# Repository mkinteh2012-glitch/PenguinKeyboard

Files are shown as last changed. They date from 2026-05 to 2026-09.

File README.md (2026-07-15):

# PenguinKeyboard
This is a 84 key keyboard built by @penguinmo   
Extra features on this keyboard are none! there isn't any :)  
I built this because i liked making a macropad and it's the samething as a keyboard!

## PICTURES






  





NOTE: for the Keyboard there is no source CAD because it is exported from kicad

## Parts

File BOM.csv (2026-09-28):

Item | Suplier | Quantity | Price | Shipping | Total
PCB | JLCPCB | 5 | 22.5 | 2.48
3D Print Parts | Print Legion | 1 set | 0 | 0 | going to but them made locally
Anti Slip Grip | Aliexpress | 1 set | 2.59 | 3.1
HeatSink Insert | Aliexpress | 1 set | 2.1 | N/A
Cable | Aliexpress | 1 | 2.27 | N/A
Screw m3 | Aliexpress | 1 set | 4.7 | N/A
stabilizers | Aliexpress | 1 set | 7.32 | N/A
Keycap | Aliexpress | 1 set | 23.31 | N/A
Pin Header | Aliexpress | 1 set | 2.31 | N/A
Pi Pico | Aliexpress | 1 | 4.28
Switches | Aliexpress | 100 | 15.78 | N/A
Diodes | Aliexpress | 100 | 2.4 |  | 98

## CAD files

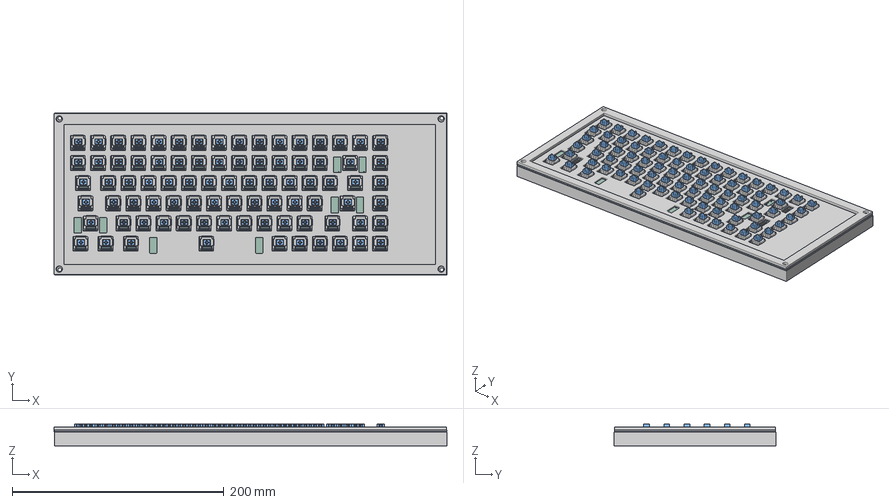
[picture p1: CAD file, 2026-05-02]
CAD/Keyboard+Assembled.stp
371.5 x 153.0 x 20.4 mm
Button x 84
Pins x 84
PenguinKeyboard 1.83.1
PenguinKeyboard 1.83.2
D_DO-35_SOD27_P7.62mm_Horizontal x 84
PenguinKeyboard_PCB

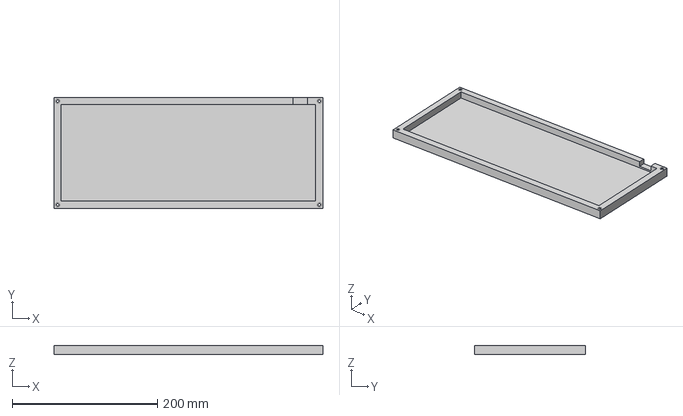
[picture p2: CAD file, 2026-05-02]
CAD/KeyboardBottom.step
371.0 x 153.0 x 13.1 mm

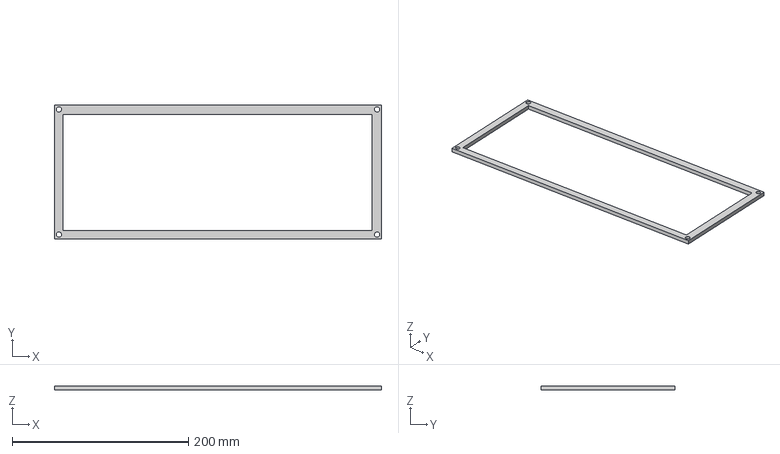
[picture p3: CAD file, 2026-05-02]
CAD/KeyboardBezel.step
371.0 x 152.0 x 5.00 mm

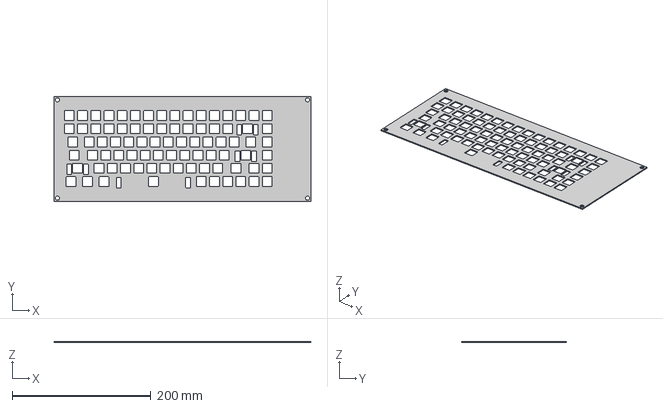
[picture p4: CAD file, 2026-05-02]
CAD/KeyboardPlate.step
371.0 x 152.0 x 1.50 mm

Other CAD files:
CAD/KeyboardPCB.step
CAD/Keyboard Assembled.f3z
CAD/KeyboardBezel.f3d
CAD/KeyboardBottom.f3d
CAD/KeyboardPlate.f3d

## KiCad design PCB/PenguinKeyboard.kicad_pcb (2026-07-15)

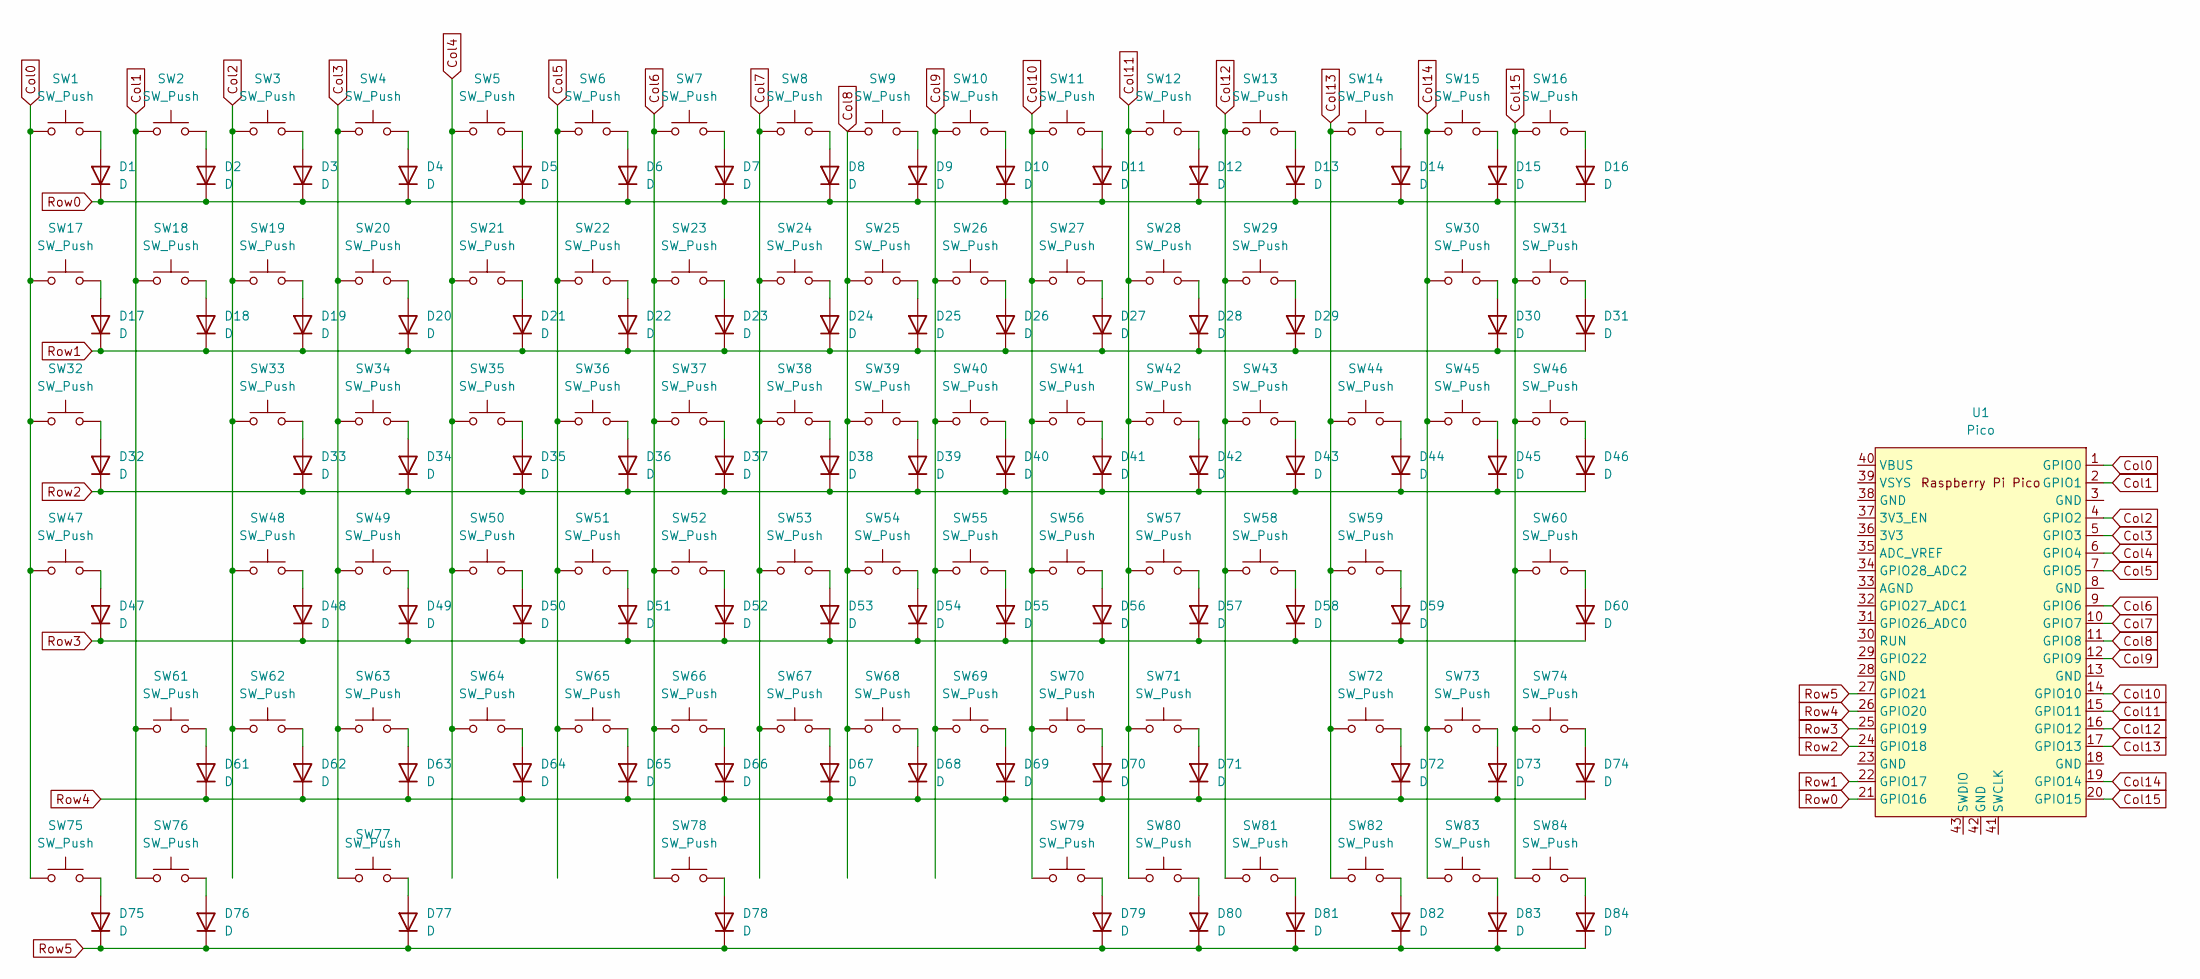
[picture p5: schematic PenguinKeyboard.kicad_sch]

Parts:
D1, D2, D3, D4, D5, D6, D7, D8, D9, D10, D11, D12, D13, D14, D15, D16, D17, D18, D19, D20, D21, D22, D23, D24, D25, D26, D27, D28, D29, D30, D31, D32, D33, D34, D35, D36, D37, D38, D39, D40, D41, D42, D43, D44, D45, D46, D47, D48, D49, D50, D51, D52, D53, D54, D55, D56, D57, D58, D59, D60, D61, D62, D63, D64, D65, D66, D67, D68, D69, D70, D71, D72, D73, D74, D75, D76, D77, D78, D79, D80, D81, D82, D83, D84: D; D_DO-35_SOD27_P7.62mm_Horizontal
SW1, SW2, SW3, SW4, SW5, SW6, SW7, SW8, SW9, SW10, SW11, SW12, SW13, SW14, SW15, SW16, SW17, SW18, SW19, SW20, SW21, SW22, SW23, SW24, SW25, SW26, SW27, SW28, SW29, SW30, SW31, SW32, SW33, SW34, SW35, SW36, SW37, SW38, SW39, SW40, SW41, SW42, SW43, SW44, SW45, SW46, SW47, SW48, SW49, SW50, SW51, SW52, SW53, SW54, SW55, SW56, SW57, SW58, SW59, SW60, SW61, SW62, SW63, SW64, SW65, SW66, SW67, SW68, SW69, SW70, SW71, SW72, SW73, SW74, SW75, SW76, SW77, SW78, SW79, SW80, SW81, SW82, SW83, SW84: SW_Push; SW_Cherry_MX_1.00u_PCB
U1: Pico; RPi_Pico_SMD_TH

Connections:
Col0: SW1.1, SW17.1, SW32.1, SW47.1, SW75.1, U1.1 (GPIO0)
Col1: SW2.1, SW18.1, SW61.1, SW76.1, U1.2 (GPIO1)
Col2: SW3.1, SW19.1, SW33.1, SW48.1, SW62.1, U1.4 (GPIO2)
Col3: SW4.1, SW20.1, SW34.1, SW49.1, SW63.1, SW77.1, U1.5 (GPIO3)
Col4: SW5.1, SW21.1, SW35.1, SW50.1, SW64.1, U1.6 (GPIO4)
Col5: SW6.1, SW22.1, SW36.1, SW51.1, SW65.1, U1.7 (GPIO5)
Col6: SW7.1, SW23.1, SW37.1, SW52.1, SW66.1, SW78.1, U1.9 (GPIO6)
Col7: SW8.1, SW24.1, SW38.1, SW53.1, SW67.1, U1.10 (GPIO7)
Col8: SW9.1, SW25.1, SW39.1, SW54.1, SW68.1, U1.11 (GPIO8)
Col9: SW10.1, SW26.1, SW40.1, SW55.1, SW69.1, U1.12 (GPIO9)
Col10: SW11.1, SW27.1, SW41.1, SW56.1, SW70.1, SW79.1, U1.14 (GPIO10)
Col11: SW12.1, SW28.1, SW42.1, SW57.1, SW71.1, SW80.1, U1.15 (GPIO11)
Col12: SW13.1, SW29.1, SW43.1, SW58.1, SW81.1, U1.16 (GPIO12)
Col13: SW14.1, SW44.1, SW59.1, SW72.1, SW82.1, U1.17 (GPIO13)
Col14: SW15.1, SW30.1, SW45.1, SW73.1, SW83.1, U1.19 (GPIO14)
Col15: SW16.1, SW31.1, SW46.1, SW60.1, SW74.1, SW84.1, U1.20 (GPIO15)
unnamed: D1.2 (A), SW1.2
unnamed: D2.2 (A), SW2.2
unnamed: D3.2 (A), SW3.2
unnamed: D4.2 (A), SW4.2
unnamed: D5.2 (A), SW5.2
unnamed: D6.2 (A), SW6.2
unnamed: D7.2 (A), SW7.2
unnamed: D8.2 (A), SW8.2
unnamed: D9.2 (A), SW9.2
unnamed: D10.2 (A), SW10.2
unnamed: D11.2 (A), SW11.2
unnamed: D12.2 (A), SW12.2
unnamed: D13.2 (A), SW13.2
unnamed: D14.2 (A), SW14.2
unnamed: D15.2 (A), SW15.2
unnamed: D16.2 (A), SW16.2
unnamed: D17.2 (A), SW17.2
unnamed: D18.2 (A), SW18.2
unnamed: D19.2 (A), SW19.2
unnamed: D20.2 (A), SW20.2
unnamed: D21.2 (A), SW21.2
unnamed: D22.2 (A), SW22.2
unnamed: D23.2 (A), SW23.2
unnamed: D24.2 (A), SW24.2
unnamed: D25.2 (A), SW25.2
unnamed: D26.2 (A), SW26.2
unnamed: D27.2 (A), SW27.2
unnamed: D28.2 (A), SW28.2
unnamed: D29.2 (A), SW29.2
unnamed: D30.2 (A), SW30.2
unnamed: D31.2 (A), SW31.2
unnamed: D32.2 (A), SW32.2
unnamed: D33.2 (A), SW33.2
unnamed: D34.2 (A), SW34.2
unnamed: D35.2 (A), SW35.2
unnamed: D36.2 (A), SW36.2
unnamed: D37.2 (A), SW37.2
unnamed: D38.2 (A), SW38.2
unnamed: D39.2 (A), SW39.2
unnamed: D40.2 (A), SW40.2
unnamed: D41.2 (A), SW41.2
unnamed: D42.2 (A), SW42.2
unnamed: D43.2 (A), SW43.2
unnamed: D44.2 (A), SW44.2
unnamed: D45.2 (A), SW45.2
unnamed: D46.2 (A), SW46.2
unnamed: D47.2 (A), SW47.2
unnamed: D48.2 (A), SW48.2
unnamed: D49.2 (A), SW49.2
unnamed: D50.2 (A), SW50.2
unnamed: D51.2 (A), SW51.2
unnamed: D52.2 (A), SW52.2
unnamed: D53.2 (A), SW53.2
unnamed: D54.2 (A), SW54.2
unnamed: D55.2 (A), SW55.2
unnamed: D56.2 (A), SW56.2
unnamed: D57.2 (A), SW57.2
unnamed: D58.2 (A), SW58.2
unnamed: D59.2 (A), SW59.2
unnamed: D60.2 (A), SW60.2
unnamed: D61.2 (A), SW61.2
unnamed: D62.2 (A), SW62.2
unnamed: D63.2 (A), SW63.2
unnamed: D64.2 (A), SW64.2
unnamed: D65.2 (A), SW65.2
unnamed: D66.2 (A), SW66.2
unnamed: D67.2 (A), SW67.2
unnamed: D68.2 (A), SW68.2
unnamed: D69.2 (A), SW69.2
unnamed: D70.2 (A), SW70.2
unnamed: D71.2 (A), SW71.2
unnamed: D72.2 (A), SW72.2
unnamed: D73.2 (A), SW73.2
unnamed: D74.2 (A), SW74.2
unnamed: D75.2 (A), SW75.2
unnamed: D76.2 (A), SW76.2
unnamed: D77.2 (A), SW77.2
unnamed: D78.2 (A), SW78.2
unnamed: D79.2 (A), SW79.2
unnamed: D80.2 (A), SW80.2
unnamed: D81.2 (A), SW81.2
unnamed: D82.2 (A), SW82.2
unnamed: D83.2 (A), SW83.2
unnamed: D84.2 (A), SW84.2
Row0: D1.1 (K), D2.1 (K), D3.1 (K), D4.1 (K), D5.1 (K), D6.1 (K), D7.1 (K), D8.1 (K), D9.1 (K), D10.1 (K), D11.1 (K), D12.1 (K), D13.1 (K), D14.1 (K), D15.1 (K), D16.1 (K), U1.21 (GPIO16)
Row1: D17.1 (K), D18.1 (K), D19.1 (K), D20.1 (K), D21.1 (K), D22.1 (K), D23.1 (K), D24.1 (K), D25.1 (K), D26.1 (K), D27.1 (K), D28.1 (K), D29.1 (K), D30.1 (K), D31.1 (K), U1.22 (GPIO17)
Row2: D32.1 (K), D33.1 (K), D34.1 (K), D35.1 (K), D36.1 (K), D37.1 (K), D38.1 (K), D39.1 (K), D40.1 (K), D41.1 (K), D42.1 (K), D43.1 (K), D44.1 (K), D45.1 (K), D46.1 (K), U1.24 (GPIO18)
Row3: D47.1 (K), D48.1 (K), D49.1 (K), D50.1 (K), D51.1 (K), D52.1 (K), D53.1 (K), D54.1 (K), D55.1 (K), D56.1 (K), D57.1 (K), D58.1 (K), D59.1 (K), D60.1 (K), U1.25 (GPIO19)
Row4: D61.1 (K), D62.1 (K), D63.1 (K), D64.1 (K), D65.1 (K), D66.1 (K), D67.1 (K), D68.1 (K), D69.1 (K), D70.1 (K), D71.1 (K), D72.1 (K), D73.1 (K), D74.1 (K), U1.26 (GPIO20)
Row5: D75.1 (K), D76.1 (K), D77.1 (K), D78.1 (K), D79.1 (K), D80.1 (K), D81.1 (K), D82.1 (K), D83.1 (K), D84.1 (K), U1.27 (GPIO21)

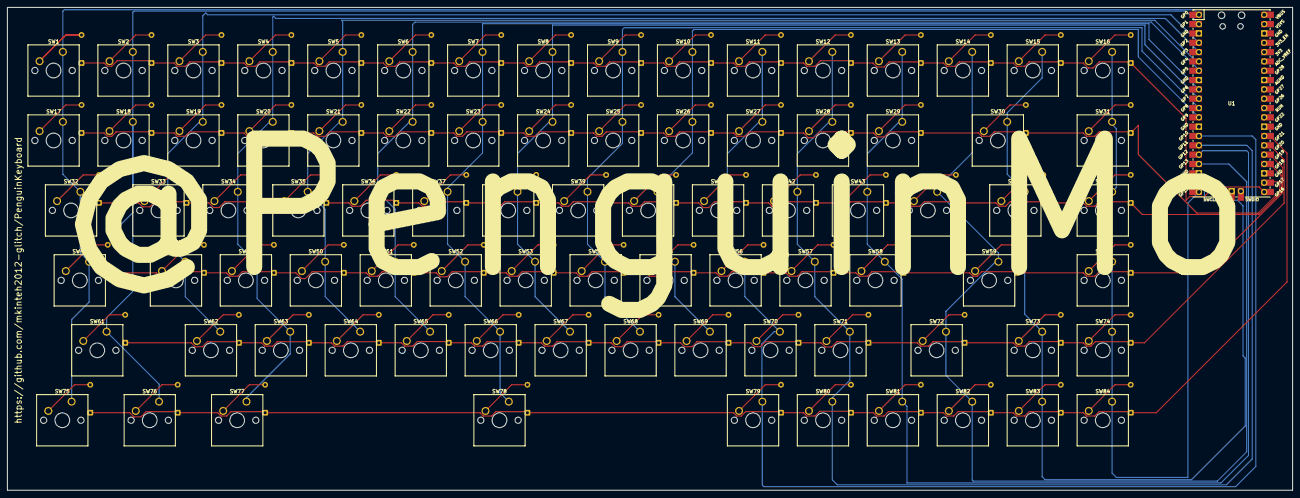
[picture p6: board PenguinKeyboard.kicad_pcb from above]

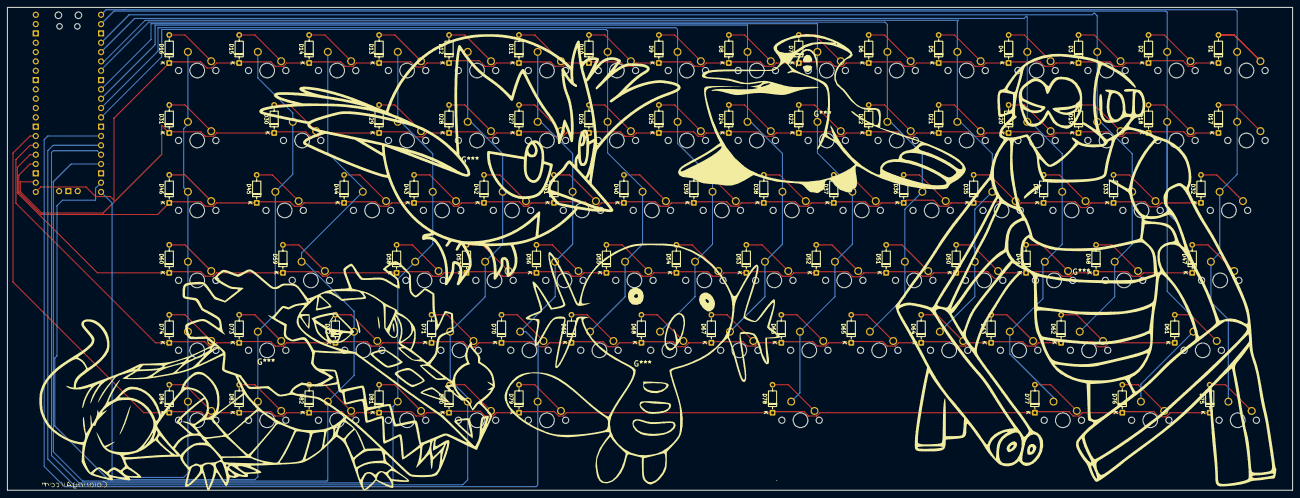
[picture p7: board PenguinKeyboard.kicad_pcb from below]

Board: 2 copper layers, 350.0 x 131.5 mm, 169 parts (84 on the bottom side), 106 nets.

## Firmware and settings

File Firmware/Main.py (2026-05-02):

#Made by Penguinmo
import board

from kmk.kmk_keyboard import KMKKeyboard
from kmk.keys import KC
from kmk.scanners import DiodeOrientation

keyboard = KMKKeyboard()
#Define pin
keyboard.col_pins = (
    board.GP0, board.GP1, board.GP2, board.GP3, board.GP4, board.GP5, 
    board.GP6, board.GP7, board.GP8, board.GP9, board.GP10, board.GP11, 
    board.GP12, board.GP13, board.GP14, board.GP15
)
keyboard.row_pins = (
    board.GP16, board.GP17, board.GP18, board.GP19, board.GP20, board.GP21
)

# Diode Dir
keyboard.diode_orientation = DiodeOrientation.COL2ROW

# 3  Keymap what goes where!
keyboard.keymap = [
    [
        KC.ESC,  KC.F1,   KC.F2,   KC.F3,   KC.F4,   KC.F5,   KC.F6,   KC.F7,   KC.F8,   KC.F9,   KC.F10,  KC.F11,  KC.F12,  KC.PSCR, KC.SLCK, KC.PAUS,
        KC.GRV,  KC.N1,   KC.N2,   KC.N3,   KC.N4,   KC.N5,   KC.N6,   KC.N7,   KC.N8,   KC.N9,   KC.N0,   KC.MINS, KC.EQL,  KC.BSPC, KC.HOME, KC.NO,
        KC.TAB,  KC.Q,    KC.W,    KC.E,    KC.R,    KC.T,    KC.Y,    KC.U,    KC.I,    KC.O,    KC.P,    KC.LBRC, KC.RBRC, KC.BSLS, KC.PGUP, KC.NO,
        KC.CAPS, KC.A,    KC.S,    KC.D,    KC.F,    KC.G,    KC.H,    KC.J,    KC.K,    KC.L,    KC.SCLN, KC.QUOT, KC.ENT,  KC.PGDN, KC.NO,   KC.NO,
        KC.LSFT, KC.Z,    KC.X,    KC.C,    KC.V,    KC.B,    KC.N,    KC.M,    KC.COMM, KC.DOT,  KC.SLSH, KC.RSFT, KC.UP,   KC.END,  KC.NO,   KC.NO,
        KC.LCTL, KC.LGUI, KC.LALT, KC.NO,   KC.NO,   KC.SPC,  KC.NO,   KC.NO,   KC.RALT, KC.RCTL, KC.LEFT, KC.DOWN, KC.RGHT, KC.NO,   KC.NO,   KC.NO,
    ]
]

if __name__ == '__main__':
    keyboard.go()

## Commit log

2026-01-04 Enhance README with additional sections
    Added sections for Pictures, Schematic, and PCB to README.
2026-01-13 Update and rename KeyboardBottom.step to CAD/KeyboardBottom.step
    [KeyboardBottom.step]
2026-05-02 Add note regarding keyboard CAD source
    Added note about the absence of source CAD for the keyboard.
2026-05-03 Rename PicoBoard BOM - Sheet1.csv to PicoBoard BOM.csv
    [PicoBoard BOM.csv]
2026-05-03 Rename PicoBoard BOM.csv to BOM.csv
    [BOM.csv]
2026-07-15 Fixed the raspberry pi positoining
    [PenguinKeyboard.kicad_pcb]
2026-09-28 Modify BOM.csv with updated shipping and totals
    Updated shipping cost for '3D Print Parts' and adjusted total for 'Diodes'.
    [BOM.csv]
